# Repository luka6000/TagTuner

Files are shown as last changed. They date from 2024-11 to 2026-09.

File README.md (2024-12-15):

# TagTuner music player
TagTuner is a device that enables you to access music playlists or albums using NFC tags.\
It only works when integrated with Home Assistant media players and the Music Assistant music library is optional. This setup seamlessly blends your digital only music collection with the tactile experience of playing a physical record, tape or cd.\
Physical music media offer several advantages:

- it's easy
- it's fast
- it's inclusive

TagTuner is made with [ESPHome](https://www.esphome.io) and includes

- an NFC reader
- a dial
- a button
- a multicolor LED light

All of this is housed in a sleek, custom design case.
B71AED4C-08D7-4F52-AC81-285DC6743BAC

D1-Custom version is only 16mm high
66AA4F85-2C12-4B6F-A300-D6C1CED9CAEC_1_105_c

Here is an exploded view of the TagTuner 3D model with a round tag card \
35F8BCBF-CFB4-4F8B-A8F3-9931829DD101

## Getting started
To start using TagTuner, you’ll need the following:
- [Home Assistant](https://www.home-assistant.io) 2024.x
- [Music Assistant](https://music-assistant.io) 2.x or [Sonos](https://www.sonos.com/) speaker 
- configured MAss music [library](https://music-assistant.io/usage/#the-library) and/or a streaming subscription 
- TagTuner device configured in HAss
- Programmable NTAG213/215/216 tags

8D01B378-9F47-4FF3-8D71-280600690BE8_1_102_a

Assuming you already have Home Assistant (HAss) with Music Assistant (MAss) or Sonos set up and running, TagTuner supports [Improv via Serial](https://esphome.io/components/improv_serial) for Wi-Fi configuration.\
If the Wi-Fi connection is misconfigured, the device will start a Wi-Fi access point, allowing you to connect and set the password.\
Home Assistant will automatically detect your new TagTuner as ESPhome device.\
In the Diagnostic panel of TagTuner you can see detailed state of your device.\
Simply place any NFC tag and watch Status messages.\
A2F404BB-9D49-482E-803A-38D39FF03134

1CE9F457-F305-4B00-A466-14A5B7033EF4_1_102_a

## Using TagTuner
TagTuner relies heavily on Home Assistant automation. To get it working, import **TagTuner for HAss** blueprint



Create automation with this blueprint.\
Select your TagTuner device (you can have more than one!) and media player that will be your speaker \
AA88EF99-C0A6-40CE-A8F9-60A0C926069F

B459D72A-3B97-4AFB-BF86-19F3298A521F_1_102_a

### Playing music
Place your tag flat on the TagTuner or use the slot to position it nicely.\
TagTuner will read the tag and send the playlist information to Home Assistant. Using automation, HAss will play music on the speaker you've set up for this TagTuner.

### Button operations
**Single click**: next \
**Double click**: play/pause \
**Long click** (>1s): mute/unmute

### Volume control
Rotate the dial left: **volume down**. \
Rotate the dial right: **volume up**. 

### Feedback
Watch the LED light in the button: \
**white blink**: operation confirmed \
**flashing red**: writing operation in progress \
**flashing green**: writing success 

### Diagnostic
Check the Diagnostic->Status messages on the device page in Home Assistant.\
The ladybug icon is your guide.

AA29C1D0-BE96-452C-B2BF-FDD8AF05B9F1_1_102_a

## How to get tags for TagTuner
### Buy tags
Choose NTAG215 (504 bytes) or NTAG216 (888 bytes) tags if you want to include the playlist name and artist. Otherwise, NTAG213 (144 bytes) will suffice for just links to playlists

- [Plain white cards](https://s.click.aliexpress.com/e/_Deb0eeV)
- [Wooden cards](https://s.click.aliexpress.com/e/_DdGYnJf)
- [Round stickers](https://s.click.aliexpress.com/e/_DB8U8dB)

Stickers can be used with 3d printed cards or any other object you can place on your TagTuner to play music.\
I use Canon KC-18IF card-sized labels to customize my wooden NFC cards.

### Program tags for Music Assistant
If your speaker is one of Music Assistant media players, your tags need to have a MAss URI.\
[Here](https://music-assistant.io/faq/how-to/#get-the-uri) you can find instructions on how to get URI for the playlist or album you want.

On the TagTuner device page, you'll find all the fileds nesesary to write the playlist URI to your tag \
38842E5D-4B81-4B88-8815-FD35B67D8357

Minimum information needed is URI.\
Fill in the Playlist URI -> click _Write Tag_ -> LED starts flashing red -> Place the tag on TagTuner \
Successful writing will be confirmed with green light.\
Check Diagnostic->Status for any additional information.

### Program tags for Sonos
If your speaker is Sonos media player, your tags can have a plain HTTP playlist URL.\
[Here](https://support.apple.com/en-us/118235) you can find instructions on how to get the album or playlist url for Apple Music. Just copy it.\
It should work the same with [Spotify](https://support.spotify.com/us/article/share-from-spotify)

On the TagTuner device page, you'll find all the fileds nesesary to write the playlist URL (URI) to your tag \
15B48F29-212B-4739-B62A-51EE45BEE9E9

Minimum information needed is URL.\
Fill in the Playlist URL -> click _Write Tag_ -> LED starts flashing red -> Place the tag on TagTuner \
Successful writing will be confirmed with green light.\
Check Diagnostic->Status for any additional information.

### Other options
You can also write your tags with any NFC NDEF tag writer, such as NXP NFC TagWriter for [iOS](https://apps.apple.com/us/app/nfc-tagwriter-by-nxp/id1246143221) or [Android](https://play.google.com/store/apps/details?id=com.nxp.nfc.tagwriter)\

 or 


### More options
#### for Sonos
You can also play any Sonos app favorite playlist, album, or station!\
Simply write the name of the playlist or station exactly as it appears in the Sonos app.\
Then, enter sonos-2:// in the URI field.\
864038B7-970D-4120-AF52-DD503CA11BEE

#### for read-only tags
If you have any read-only tags that can be read by TagTuner (give it a try to check), you can use them too!\
To set the playlist URL, place it as the name of the tag in HAss panel \
\
D88754F6-5199-47EA-B71D-4B262B060160

Any tag id read by TagTuner will be pushed to HAss [blueprint](#using-tagtuner) automation.

8C579E90-8189-417C-8D1E-49295F2F88D9_1_102_a

## Build your own TagTuner
Choose and print your enclosure with preffered colors and surface patterns
150898D9-AA77-4470-9DA3-2A89EE304011

I suggest a cool white base and a dark front plate with a nice carbon fibre pattern.

### Parts for Atom grove version
This version is focused on minimum soldering since it's based on Grove parts and connectors
- [m5stack Atom Echo](https://s.click.aliexpress.com/e/_DCenStP) controller
- [pn532](https://s.click.aliexpress.com/e/_De8uw89) NFC reader
- [grove angle connectors](https://s.click.aliexpress.com/e/_DDF07mN)
- [grove cables](https://s.click.aliexpress.com/e/_DEA2jSV)
- [grove rotary encoder](https://www.seeedstudio.com/Grove-Encoder.html?sensecap_affiliate=3ftNV1d&referring_service=link)
#### Grove wiring
First, you need to solder the [grove angle connector](https://s.click.aliexpress.com/e/_DDF07mN) to the [PN532 NFC](https://s.click.aliexpress.com/e/_De8uw89) board
CA3A603C-CE5B-4982-AF24-9E40D3E554C2_1_201_a
Remember to set the DIP switches to 10 to enable I2C.

The [SeeedStudio rotary encoder](https://www.seeedstudio.com/Grove-Encoder.html?sensecap_affiliate=3ftNV1d&referring_service=link) already has its connector. For the other end of the [cable](https://s.click.aliexpress.com/e/_DEA2jSV), simply use [grove angle connector](https://s.click.aliexpress.com/e/_DDF07mN) directly to the Atom controller\
7D603FCA-9D48-485F-8AD4-685A469D73F6_1_201_a

It's really as simple as that
8CD41A9B-E7F6-46FE-8770-5138BF0B893E_1_201_a

Everything will fit into the enclosure.\
Use short (<5mm) M2 screw for Atom and longer (10mm) M2.5 screws for everything else (nfc board, volume encoder, front plate).
BD16EF90-5222-40EF-A131-2C27C6EE5493_1_102_o

### Parts for D1-Custom version
This version requires a bit more soldering but allows the knob to be used as a button.
- [esp32 D1 mini](https://s.click.aliexpress.com/e/_DkyEAwt) controller with USBC
- [pn532](https://s.click.aliexpress.com/e/_De8uw89) NFC reader
- [hw040](https://s.click.aliexpress.com/e/_DlIIMtn) rotary encoder

Remember to set the pn532 DIP switches to 10 to enable I2C (as described above).

#### Wiring D1-Custom
pn532 connector:
- GND: GND
- VCC: VCC (+5V)
- SDA/TXD: IO21
- SCL/RXD: IO22

hw040 connector:
- CLK: IO18
- DT: IO19
- SW: IO23
- +: +3.3V
- GND: GND

BCAC91FD-93C7-45B1-BD3F-C07717A7AF5C_1_201_a

ESP23 D1 mini will fit perfectly into the bottom part braces


Built-in LED is used as confirmation light
85EAFCF9-9730-4185-8AF7-A039E5863FB1_1_105_c

### Case options
- [3d models](https://github.com/luka6000/TagTuner/tree/main/3d%20models): Atom Echo Grove version 3d models
- [printables](https://www.printables.com/model/1109660-tagtuner-d1-custom1): 16mm D1-Custom version model

### Firmware options

- [tagtuner-atom-grove.yaml](https://github.com/luka6000/TagTuner/blob/main/tagtuner-atom-grove.yaml): based on m5stack Atom Echo and grove connectors
- [tagtuner-atom-grove-ble.yaml](https://github.com/luka6000/TagTuner/blob/main/tagtuner-atom-grove-ble.yaml): m5stack Atom Echo + Bluetooth & BLE proxy, no media player, ESP-IDF framework. This is current default install
- [tagtuner-for-tagreader.yaml](https://github.com/luka6000/TagTuner/blob/main/tagtuner-for-tagreader.yaml): TagTuner firmware for [Adonno tagreader](https://github.com/adonno/tagreader) device (buzzer only, no led support)
- [tagtuner-D1-custom1.yaml](https://github.com/luka6000/TagTuner/blob/main/tagtuner-D1-custom1.yaml): ESP32 D1 mini with HW-040 rotary encoder and button. Bluetooth & BLE proxy, ESP-IDF framework

## Help me
OK, I can try. Please choose your preferred way of communication

- [reddit](https://www.reddit.com/r/homeassistant/comments/1go2l9l/tagtuner_nfc_music_player_showoff/)
- [HAss community](https://community.home-assistant.io/t/tagtuner-music-player-for-nfc-tags/787529)
- [MAss discord](https://discord.com/channels/753947050995089438/1300230612958838908/1300230612958838908)

## A little history
It all began one day back in 2022. \
I've seen all those cool NFC jukebox projects but found myself too lazy to automate each tag individually. \
So, I [contributed](https://github.com/adonno/tagreader/commits?author=luka6000) to the Adonno [tagreader](https://github.com/adonno/tagreader) project to enable it to push playlist URLs as HAss events. \
[Here's](https://community.home-assistant.io/t/tagreader-jukebox-old-dog-new-tricks/407855) original story posted on Home Assistant communities.\
Since then, TagTuner has been completely refactored and physically redesigned.

## Disclaimer
All of this is my personal hobby project, available for free download and personal use. If you’d like to support me with a coffee, beer, filament, or electronic parts, feel free to use PayPal
[paypal.me/lukagra](http://paypal.me/lukagra)

Links to parts listed above are affiliate links, which allow me to earn a small commission from your purchase. Thank you! 🙏

My work, including yaml files, 3d model and documentation, is licensed under \
[Creative Commons (4.0 International License) Attribution—Noncommercial—Share Alike \
](http://creativecommons.org/licenses/by-nc-sa/4.0/)

ESPhome components modifications are licensed under ESPHome [license](https://github.com/esphome/esphome?tab=License-1-ov-file#readme)

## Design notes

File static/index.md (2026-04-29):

- [Firmware installation](#firmware-installation)
- [Getting started](#getting-started)
- [Build your own TagTuner](#build-your-own-tagtuner)
- [Using TagTuner](#using-tagtuner)
- [get tags for TagTuner](#how-to-get-tags-for-tagtuner)
- [Help](#help-me)

# TagTuner music player
TagTuner is a device that enables you to access music playlists or albums using NFC tags.\
It only works when integrated with Home Assistant media players. Music Assistant music library is optional. This setup seamlessly blends your digital only music collection with the tactile experience of playing a physical record, tape or cd.\
Physical music media offer several advantages:

- it's easy
- it's fast
- it's inclusive

TagTuner is made with [ESPHome](https://www.esphome.io) and includes

- an NFC reader
- a dial with a button
- a LED light

All of this is housed in a sleek, custom design case only 16mm high


66AA4F85-2C12-4B6F-A300-D6C1CED9CAEC_1_105_c

Here is an exploded view of the TagTuner 3D model with a round tag card \


TagTuner is a device approved by the [Made for ESPHome](https://devices.esphome.io/made-for-esphome) program.
made-for-esphome-black-on-white

Check out also the [TagTuner on HA Voice PE version](https://github.com/luka6000/TagTuner/blob/main/TagTuner-on-HA-Voice-PE.md)
2B7737D0-8398-4024-95F7-A9C97CBA63E3_1_105_c

## Firmware installation

You can use the button below to install the pre-built firmware directly to your device via USB from the browser.

<style>
  .invisible {
    visibility: hidden;
  }
  .radios li {
    list-style: none;
    line-height: 2em;
  }
</style>
<script type="module" src="https://unpkg.com/esp-web-tools@9/dist/web/install-button.js?module"></script>
<p>Select your TagTuner version</p>
<ul class="radios">
  <li>
    <label><input type="radio" name="type" value="tagtuner-xiao-esp32c6" /> XIAO Custom</label>
  </li>
  <li>
    <label><input type="radio" name="type" value="tagtuner-on-ha-voice-esp32s3" /> HA Voice PE</label>
  </li>
  <li>
    <label><input type="radio" name="type" value="tagtuner-atom-esp32" /> m5 Atom</label>
  </li>
  <li>
    <label><input type="radio" name="type" value="tagtuner-for-tagreader-esp8266" /> tagreader</label>
  </li>
  <li>
    <label><input type="radio" name="type" value="tagtuner-d1-esp32" /> D1 Custom</label>
  </li>
</ul>
<p class="button-row" align="center">
  <esp-web-install-button class="invisible"></esp-web-install-button>
</p>
<script>
  document.querySelectorAll('input[name="type"]').forEach(radio =>
    radio.addEventListener("change", () => {
      const button = document.querySelector('esp-web-install-button');
      button.manifest = `./firmware/manifest-${radio.value}.json`;
      button.classList.remove('invisible');
    }
  ));
</script>

Installer powered by [ESP Web Tools](https://esphome.github.io/esp-web-tools/)

## Getting started
To start using TagTuner, you’ll need the following:
- [Home Assistant](https://www.home-assistant.io) 2025.12.x
- [Music Assistant](https://music-assistant.io) 2.7.x or [Sonos](https://www.sonos.com/) speaker 
- configured MAss music [library](https://music-assistant.io/usage/#the-library) and/or a streaming subscription 
- TagTuner device configured in HAss
- any NFC tags or programmable NTAG213/215/216

8D01B378-9F47-4FF3-8D71-280600690BE8_1_102_a

Assuming you already have Home Assistant (HAss) with Music Assistant (MAss) or Sonos set up and running, TagTuner supports [Improv via Serial](https://esphome.io/components/improv_serial) and [Improv via BLE](https://esphome.io/components/esp32_improv) for Wi-Fi configuration.\
Home Assistant will automatically detect your new TagTuner as ESPhome device.\
In the Diagnostic panel of TagTuner you can see detailed state of your device.\
Simply place any NFC tag and watch Status messages.\
A2F404BB-9D49-482E-803A-38D39FF03134

1CE9F457-F305-4B00-A466-14A5B7033EF4_1_102_a

## Build your own TagTuner

### Case
Custom model cases are print-ready

- [printables](https://www.printables.com/model/1109660)
- [ko-fi/shop](https://ko-fi.com/s/ce428ab53f)

Choose and print your enclosure with preferred colors and surface patterns. \
I suggest a cool-white (signal white) base and a dark front plate with a nice carbon fibre pattern.
D7EFA920-1D9A-4D65-AD23-4F0A2328A510_1_105_c

### BOM for XIAO-Custom version
- [XIAO esp32-c6](https://s.click.aliexpress.com/e/_c3hnW7jV) controller with built-in antenna
- [pn532](https://s.click.aliexpress.com/e/_c3l9MKHr) NFC reader
- [grove angle connectors](https://s.click.aliexpress.com/e/_c3xcepEd)
- [grove cables](https://s.click.aliexpress.com/e/_c3rtIVGR)
- [hw040](https://s.click.aliexpress.com/e/_c3vSH4wJ) rotary encoder
- [dupont cables](https://s.click.aliexpress.com/e/_c4FUMZi7) for hw040
- [M2.5 10mm](https://s.click.aliexpress.com/e/_c3gFU5Zv) screws

#### Wiring XIAO-Custom
pn532 connector (use grove cable):
- GND: GND (bottom cable)
- VCC: VBUS (+5V, bottom cable)
- SDA/TXD: D4
- SCL/RXD: D5

hw040 connector (use dupont cable):
- CLK: D8
- DT: D9
- SW: D10
- +: 3V3 (+3.3V)
- GND: GND



Route and solder the VCC (red) and GND (white) wires along the bottom side of XIAO to ensure the front LED remains unobstructed.

XIAO will fit perfectly into the bottom part braces


Built-in LED is used as confirmation light. Print the led peg with clear filament and it will give great results \


I prefer soldering the grove angle connector to the PN532 NFC board
CA3A603C-CE5B-4982-AF24-9E40D3E554C2_1_201_a

Just use the force ;-)
528C987E-321C-4D8D-81F6-45F3D853613B_1_201_a

Remember to set the DIP switches to 10 to enable I2C. Correct switches position for I2c is marked by yellow lines.

Everything will fit into the enclosure.


Use 10mm M2.5 screws (nfc board, volume encoder, front plate).

### Firmware

- [quick start](https://luka6000.github.io/TagTuner/#installation): use pre-built firmware with [ESP Web Tools](https://esphome.github.io/esp-web-tools/) powered installer [here](https://luka6000.github.io/TagTuner/#installation)
- [tagtuner-XIAO-custom.yaml](https://github.com/luka6000/TagTuner/blob/main/tagtuner-XIAO-custom.yaml): XIAO ESP32-C6 with HW-040 rotary encoder and button. Bluetooth & BLE proxy, ESP-IDF framework

### Other options
- [D1 mini](https://github.com/luka6000/TagTuner/blob/main/TagTuner-D1.md): TagTuner Custom1 based on the ESP32 D1 Mini; previously my preferred version but dropped in favor of the XIAO because of the poor quality of available D1 boards
- [HA Voice PE version](https://github.com/luka6000/TagTuner/blob/main/TagTuner-on-HA-Voice-PE.md): TagTuner on HA Voice PE device
- [tagtuner-for-tagreader.yaml](https://github.com/luka6000/TagTuner/blob/main/tagtuner-for-tagreader.yaml): TagTuner firmware for [Adonno tagreader](https://github.com/adonno/tagreader) device (buzzer only, no led support)
- [Atom version](https://github.com/luka6000/TagTuner/blob/main/TagTuner-Atom.md): based on m5stack Atom Echo and grove connectors; free model case but much thicker (23.5mm)
- [Compact Case](https://www.printables.com/model/1165511-tagtuner-compact-case-rfid-nfc-scanner-home-assist): card-sized case by Youddha (thank you!)

## Using TagTuner
TagTuner relies heavily on Home Assistant automation. To get it working, import **TagTuner for HAss** blueprint



Create automation with this blueprint.\
Select your TagTuner device (you can have more than one!) and media player that will be your speaker \
AA88EF99-C0A6-40CE-A8F9-60A0C926069F

I do a monthly updates of the blueprint. You can watch my repo to get email notifications. \
Current list of features:

- separate settings for MAss player and HAss player (http sources). If you don't need double setting, just set the same player in both
- Stop music on tag removed: choose if you want this
- Announce every playlist: you can choose your TTS engine and TagTuner will use your speaker to read artist and playlist names
- Shuffle every playlist: choose if you want this. You can also add '/shuffle' (without quotes or spaces) at the end of the source URI to shuffle just this album
- Volume limiter: to limit the maximum volume set with TagTuner knob (kids friendly!)
- Default volume on start playing
- Notify about version mismatch: shoose if you want HA dashboard notification that your blueprint version is to new vs your TagTuner yaml firmware. Currently there are no breaking changes so this is future proofing the blueprint and your experience



B459D72A-3B97-4AFB-BF86-19F3298A521F_1_102_a

### Playing music
Place your tag flat on the TagTuner or use the slot to position it nicely.\
TagTuner will read the tag and send the playlist information to Home Assistant. Using automation, HAss will play music on the speaker you've set up for this TagTuner.

### Button operations
**Single click**: next \
**Double click**: play/pause \
**Long click** (>1s): mute/unmute \
**Triple click**: previous

### Volume control
Rotate the dial left: **volume down** \
Rotate the dial right: **volume up** 

### Feedback
Watch the LED light in the button: \
**blink**: operation confirmed \
**flashing constant**: writing operation in progress \
**flashing few times**: operation success

XIAO-Custom has a single color led so it's only blinking but it's really easy to understand what's going on. Use HAss device Diagnostic dashboard in case you would need status info.

### Diagnostic
Check the Diagnostic->Status messages on the device page in Home Assistant.\
The ladybug icon is your guide.

AA29C1D0-BE96-452C-B2BF-FDD8AF05B9F1_1_102_a

## How to get tags for TagTuner
### Upcycle tags you already have
Use whatever nfc tags you have that work with PN532. \
Simply scan them with TagTuner and check you HA tags panel. \
Try Amiibos, NFC rings, work badges, etc. \
You can even [recycle a Sonicare](https://github.com/luka6000/TagTuner/blob/main/Recycled-tags.md) toothbrush head 🤙

Check [the read-only tags](https://github.com/luka6000/TagTuner/tree/main?tab=readme-ov-file#for-read-only-tags) section below.

### Buy tags
Choose NTAG215 (504 bytes) or NTAG216 (888 bytes) tags if you want to include the playlist name and artist. Otherwise, NTAG213 (144 bytes) will suffice for just links to playlists

- [Plain white cards](https://s.click.aliexpress.com/e/_Deb0eeV)
- [Wooden cards](https://s.click.aliexpress.com/e/_DdGYnJf)
- [Round stickers](https://s.click.aliexpress.com/e/_DB8U8dB)

Record-like cards can be printed (model file included) or you can buy those nice looking [vinyl coasters](https://s.click.aliexpress.com/e/_ooVfjuN). Just remember to put NFC stickers on them ;-) \
Stickers can be used with 3d printed cards or any other object you can place on your TagTuner to play music.\
I use Canon KC-18IF card-sized labels to customize my wooden NFC cards.

### Program tags for Music Assistant
If your speaker is one of Music Assistant media players, your tags need to have a MAss URI.\
[Here](https://music-assistant.io/faq/how-to/#get-the-uri) you can find instructions on how to get URI for the playlist or album you want. In the latest versions you can basically copy the URI directly from the Provider details section for that media.

On the TagTuner device page, you'll find all the fileds nesesary to write the playlist URI to your tag \
38842E5D-4B81-4B88-8815-FD35B67D8357

Minimum information needed is URI.\
Fill in the Playlist URI -> click _Write Tag_ -> LED starts flashing red -> Place the tag on TagTuner \
Successful writing will be confirmed with green light.\
Check Diagnostic->Status for any additional information.

### Program tags for Sonos
If your speaker is Sonos media player, your tags can have a plain HTTP playlist URL.\
[Here](https://support.apple.com/en-us/118235) you can find instructions on how to get the album or playlist url for Apple Music. Just copy it.\
It should work the same with [Spotify](https://support.spotify.com/us/article/share-from-spotify)

On the TagTuner device page, you'll find all the fileds nesesary to write the playlist URL (URI) to your tag \
15B48F29-212B-4739-B62A-51EE45BEE9E9

Minimum information needed is URL.\
Fill in the Playlist URL -> click _Write Tag_ -> LED starts flashing red -> Place the tag on TagTuner \
Successful writing will be confirmed with green light.\
Check Diagnostic->Status for any additional information.

### Other options
You can also write your tags with any NFC NDEF tag writer, such as NXP NFC TagWriter for [iOS](https://apps.apple.com/us/app/nfc-tagwriter-by-nxp/id1246143221) or [Android](https://play.google.com/store/apps/details?id=com.nxp.nfc.tagwriter)\

 or 


### More options
#### for Sonos
You can also play any Sonos app favorite playlist, album, or station!\
Simply write the name of the playlist or station exactly as it appears in the Sonos app.\
Then, enter sonos-2:// in the URI field.\
864038B7-970D-4120-AF52-DD503CA11BEE

#### for read-only tags
If you have any read-only tags that can be read by TagTuner (give it a try to check), you can use them too!\
To set the playlist URL, place it as the name of the tag in HAss panel \
\
D88754F6-5199-47EA-B71D-4B262B060160

Any tag id read by TagTuner will be pushed to HAss [blueprint](#using-tagtuner) automation.

8C579E90-8189-417C-8D1E-49295F2F88D9_1_102_a

## Help
OK, I can try. Please choose your preferred way of communication

- [HAss community](https://community.home-assistant.io/t/tagtuner-music-player-for-nfc-tags/787529)
- [MAss discord](https://discord.com/channels/753947050995089438/1300230612958838908/1300230612958838908)
- [reddit](https://www.reddit.com/r/homeassistant/comments/1go2l9l/tagtuner_nfc_music_player_showoff/)

## A little history
It all began one day back in 2022. \
I've seen all those cool NFC jukebox projects but found myself too lazy to automate each tag individually. \
So, I [contributed](https://github.com/adonno/tagreader/commits?author=luka6000) to the Adonno [tagreader](https://github.com/adonno/tagreader) project to enable it to push playlist URLs as HAss events. \
[Here's](https://community.home-assistant.io/t/tagreader-jukebox-old-dog-new-tricks/407855) original story posted on Home Assistant communities.\
Since then, TagTuner has been completely refactored and physically redesigned.

## Disclaimer
All of this is my personal hobby project, available for free download and personal use. If you’d like to support me with a coffee, beer, filament, or electronic parts, feel free to use [paypal.me/lukagra](https://paypal.me/lukagra) or [ko-fi.com/lukagra](https://ko-fi.com/lukagra)

Links to parts listed above are affiliate links, which allow me to earn a small commission from your purchase. Thank you! 🙏

This work, including yaml files, 3d model (Atom version) and documentation, is licensed under \
[Creative Commons (4.0 International License) Attribution—Noncommercial—Share Alike \
](http://creativecommons.org/licenses/by-nc-sa/4.0/)

ESPhome components modifications are licensed under ESPHome [license](https://github.com/esphome/esphome?tab=License-1-ov-file#readme)

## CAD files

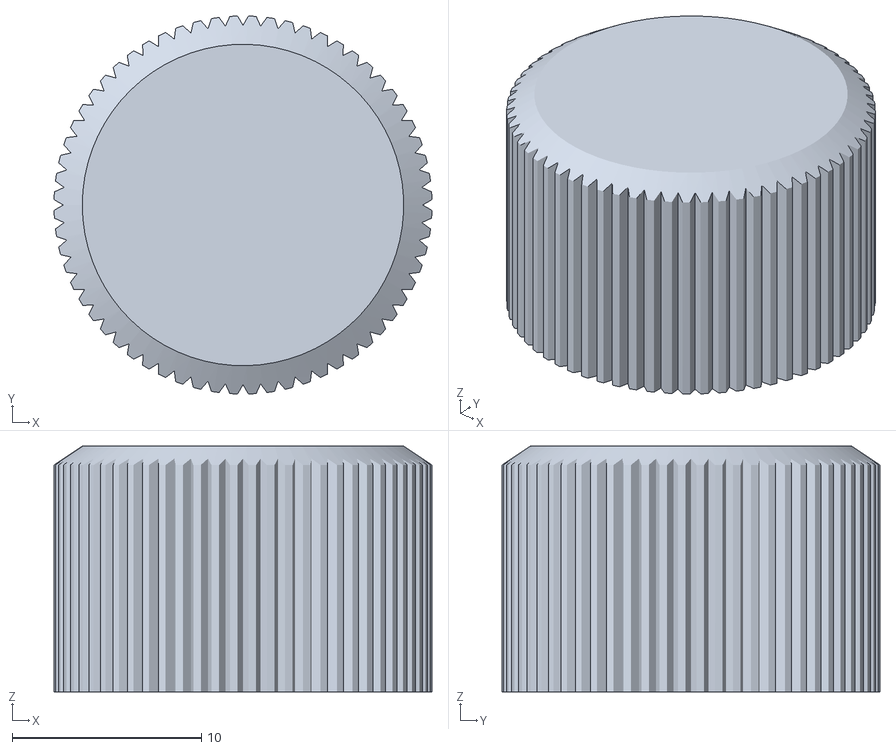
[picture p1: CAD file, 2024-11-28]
3d models/TagTunerVolumeKnob.stl
20.0 x 20.0 x 13.0

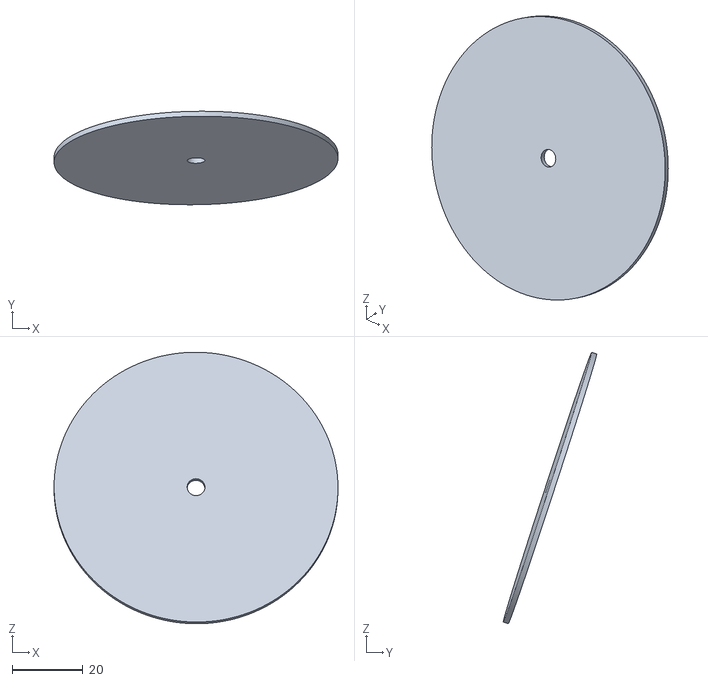
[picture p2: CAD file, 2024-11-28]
3d models/TagTunerRecordCard.stl
80.0 x 26.4 x 76.5

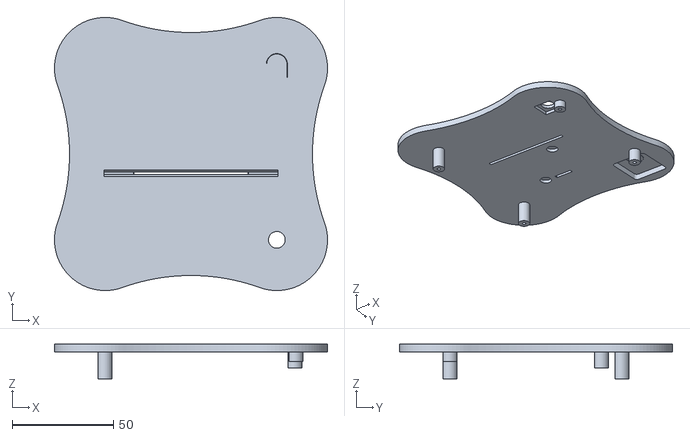
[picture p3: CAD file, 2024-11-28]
3d models/TagTunerAtomEchoGrovePlate.stl
134.9 x 134.9 x 17.2

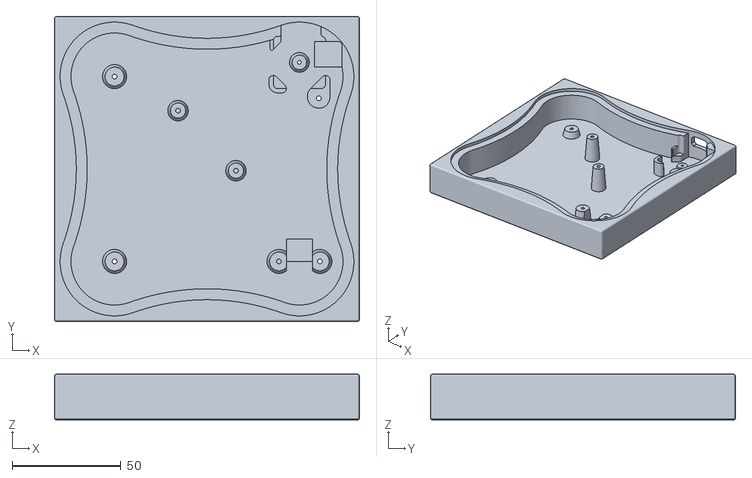
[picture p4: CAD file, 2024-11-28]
3d models/TagTunerAtomEchoGroveBase.stl
140.0 x 140.0 x 21.0

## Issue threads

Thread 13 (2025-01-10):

i2c configuration mismatch and incorrect screenshot of hardware settings nfc module

rbr101, 2025-01-10:
Hi Luka,

Nice work you did here, just tested the configuration and now printing the case.
I love the concept of a physical disk togerther with musicassistent.

I had to change the ic2 config to get it working:
```
i2c:
  id: bus_i2c
  sda: 21
  scl: 22
  scan: False
  frequency: 100kHz
  timeout: 13ms #to prevent pn532 timeout
```

Changed to:

```
i2c:
  id: bus_i2c
  scan: False
  timeout: 13ms #to prevent pn532 timeout
```

The frequency part was failing the NFC module to load (Probably because i’m using a clone NFC). Also in the screenshots in the docu the jumper setting is wrong and should be the other way around. In the screenshots SPI is selected but should be i2c.

I also found some nice mini vinyl LP’s on ali that can be used:  https://nl.aliexpress.com/item/1005008275356934.html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

My D1 esp32 does not have a green light ,  so i will probably add a ws2811 and a buzzer for feedback when writing /reading the tags.

Cheers!

luka6000, 2025-01-10:
Thanks.
Devices should hold 400kHz bus so this 100kHz is actually setting a slow bus. Hard to say why your nfc board can't keep up. Maybe set the timeout longer first.

About the screenshot: I think I know what you mean. It is set ok so I added clarification in the description
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

Nice finding with the retro vinyls. I'll add that to the options.
Good luck with your build and keep me posted.
Use latest blueprint since I do a monthly changes on that one!

Closed 2025-01-17.

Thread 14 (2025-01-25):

Issue after rebooting

pschneider87, 2025-01-25:
First of all, a huge thanks for your work. I've built everything with your manuals, and it worked very smooth.

I recently wanted to also make use of the BLE Proxy, so I decided to do a fresh start.
I've removed the esp project and added a new one, with a fresh install.

the new tagtuner.yaml which gets created already has some content:
```
esphome:
  name: tagtuner
  friendly_name: TagTuner

esp32:
  board: esp32dev
  framework:
    type: arduino

# Enable logging
logger:

# Enable Home Assistant API
api:
  encryption:
    key: "key is here"

ota:
  - platform: esphome
    password: "some password here"

wifi:
  ssid: !secret wifi_ssid
  password: !secret wifi_password

  # Enable fallback hotspot (captive portal) in case wifi connection fails
  ap:
    ssid: "Tagtuner Fallback Hotspot"
    password: "some other password"

captive_portal:
```

Is it correct to copy everything from [tagtuner-atom-grove-ble.factory.yaml](https://github.com/luka6000/TagTuner/blob/main/tagtuner-atom-grove-ble.factory.yaml) into my yaml and keep everything from my configuration? Of course I substitute the esp32: section with the one from the yaml

```
esp32:
  board: m5stack-atom
  framework:
    type: esp-idf
```

So far, everything works smooth and I can use it in the beginning.
But as soon as I unplug it and bring it to it's final destination and try to restart it, it won't come back to life.

I can connect to the tagtuner and see some logs:

```
INFO ESPHome 2024.12.4
INFO Reading configuration /config/esphome/tagtuner.yaml...
INFO Updating https://github.com/luka6000/TagTuner.git@main
INFO Starting log output from 192.168.178.164 using esphome API
INFO Successfully connected to tagtuner @ 192.168.178.164 in 0.042s
INFO Successful handshake with tagtuner @ 192.168.178.164 in 0.107s
[13:40:37][I][app:100]: ESPHome version 2024.12.4 compiled on Jan 25 2025, 13:24:46
[13:40:37][C][wifi:600]: WiFi:
[13:40:37][C][wifi:428]:   Local MAC: 14:2B:2F:A0:5D:28
[13:40:37][C][wifi:433]:   SSID: [redacted]
[13:40:37][C][wifi:436]:   IP Address: 192.168.178.164
[13:40:37][C][wifi:440]:   BSSID: [redacted]
[13:40:37][C][wifi:441]:   Hostname: 'tagtuner'
[13:40:37][C][wifi:443]:   Signal strength: -39 dB ▂▄▆█
[13:40:37][C][wifi:447]:   Channel: 1
[13:40:37][C][wifi:448]:   Subnet: 255.255.255.0
[13:40:37][C][wifi:449]:   Gateway: 192.168.178.1
[13:40:37][C][wifi:450]:   DNS1: 192.168.178.1
[13:40:37][C][wifi:451]:   DNS2: 0.0.0.0
[13:40:37][C][logger:185]: Logger:
[13:40:37][C][logger:186]:   Level: DEBUG
[13:40:37][C][logger:188]:   Log Baud Rate: 115200
[13:40:37][C][logger:189]:   Hardware UART: UART0
[13:40:37][C][captive_portal:089]: Captive Portal:
[13:40:37][C][mdns:116]: mDNS:
[13:40:37][C][mdns:117]:   Hostname: tagtuner
[13:40:37][C][esphome.ota:073]: Over-The-Air updates:
[13:40:37][C][esphome.ota:074]:   Address: tagtuner.local:3232
[13:40:37][C][esphome.ota:075]:   Version: 2
[13:40:37][C][esphome.ota:078]:   Password configured
[13:40:37][C][safe_mode:018]: Safe Mode:
[13:40:37][C][safe_mode:020]:   Boot considered successful after 60 seconds
[13:40:37][C][safe_mode:021]:   Invoke after 10 boot attempts
[13:40:37][C][safe_mode:023]:   Remain in safe mode for 300 seconds
[13:40:37][C][api:140]: API Server:
[13:40:37][C][api:141]:   Address: tagtuner.local:6053
[13:40:37][C][api:143]:   Using noise encryption: YES
[13:40:48][D][api:103]: Accepted 192.168.178.36
[13:40:48][W][component:237]: Component api took a long time for an operation (70 ms).
[13:40:48][W][component:238]: Components should block for at most 30 ms.
[13:40:48][D][api.connection:1446]: Home Assistant 2025.1.4 (192.168.178.36): Connected successfully
[13:41:15][I][safe_mode:041]: Boot seems successful; resetting boot loop counter
[13:41:15][D][esp32.preferences:114]: Saving 1 preferences to flash...
[13:41:15][D][esp32.preferences:143]: Saving 1 preferences to flash: 0 cached, 1 written, 0 failed
```

There's nothing more happening.

Any idea?

luka6000, 2025-01-25:
> First of all, a huge thanks for your work. I've built everything with your manuals, and it worked very smooth.
>

Glad it works for you as designed!

> Is it correct to copy everything from [tagtuner-atom-grove-ble.factory.yaml](https://github.com/luka6000/TagTuner/blob/main/tagtuner-atom-grove-ble.factory.yaml) into my yaml and keep everything from my configuration? Of course I substitute the esp32: section with the one from the yaml
>

No. Use just the tagtuner-atom-grove-ble.factory.yaml file.
You could leave "api" and "ota" section. Please remove "captive_portal" and "ap:" in the "wifi" section as these take a lot of memory.
Remember to flush with usb for the first time and setup wifi. Later you can use wireless update (ota).

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

These logs look pretty standar.

> There's nothing more happening.
> Any idea?

What do you mean? Is this node recognized by HAss? Please remove old tagtuner node and discover it again.
Can you see esphome.tagtuner events in the HAss Developer tools->Events (start listening for those events) after trying to scan the tag?

Closed 2025-03-21.

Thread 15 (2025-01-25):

Example URI for "ytmusic://" ? Thanks!

Youddha, 2025-01-25:
Hello,
First of all thanks a lot for the project ! I really like it and it work very nicely.

I would like to know if you could provide an example an how to find/enter the uri for **"ytmusic://"** ? And where to find the info ? I tried almost every combination of the indication given in mass docs with no luck...

Unrelated:
- I can confirm that **tidal://** and **filesystem_local://** URIs work great !
- I will soon publish a compact 3D case for the WemosD1/ESP32: [this one](https://www.printables.com/make/2350666). Hope it will help a bit user of your project that want Card-sized scanner.

luka6000, 2025-01-25:
So, first things first:

1. YTmusic support in MAss is reverse engineering private yt api. This means it is not guaranteed to be always working. In fact, it is guaranteed to fail from time to time. Here's [MAss yt docs](https://www.music-assistant.io/music-providers/youtube-music/) confirming this situation
2. Lately ytmusic was not working for me but now I've checked it is working again. I've used method described in [MAss docs](https://www.music-assistant.io/faq/how-to/#get-the-uri). Using "Music Assistant: Search Music Assistant" action in HAss I was able to get ytmusic uris like this ytmusic://track/yl3TsqL0ZPw
3. This method of getting URI is very complicated and not clear. Here is a github feature request so you can discuss it with MAss developers https://github.com/orgs/music-assistant/discussions/2311
4. In case you have problems with getting URI, please ask for support on MAss github or discord. MAss developers have their own priorities and apparently getting URI easy is one of them.
5. What I can recommend is this: set your own MAss playlist (URI will look like library://track/127) and add ytmusic tracks to it. Of course, there is no other way of getting this local URI then searching it with HAss action 🤦‍♂️🤷‍♂️ This way at least the URI is constant and on local side. As a side bonus you can change track order however you like.
6. apple_music:// URIs also work great but have to be searched for with MAss service.
7. https direct links to playlist, tracks, album and everything work great with Sonos (not using MAss at all)

Cool looking mini reader. Can I ask you to also link my main page (https://luka6000.github.io/TagTuner/) in your model description? I'm glad you enjoy using TagTuner blueprint!

Youddha, 2025-01-27:
Hello,

Thanks a lot for your detailed answer and advices. I see you have been busy on the MAss github too.
I'll try your solutions 2 and 5 asap thanks.
Lastly, I posted my model yesterday on[ Printable.com](https://www.printables.com/model/1165511-tagtuner-compact-case-rfid-nfc-scanner-home-assist) and I off course referenced your project !

_Will update on 2 and 5 soon._

Closed 2025-02-03.

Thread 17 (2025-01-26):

Compact Case available on Printable

Youddha, 2025-01-26:
Hello Luka,

I really like your project and I designed a compact case for it. Here it is:
[https://www.printables.com/model/1165511-tagtuner-compact-case-rfid-nfc-scanner-home-assist](https://www.printables.com/model/1165511-tagtuner-compact-case-rfid-nfc-scanner-home-assist)

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

I understand it is not an "issue" per say but I don't know how to reach you in another way ^^

Hope it helps your project !

luka6000, 2025-02-03:
made it part of the new main readme page. Thank you!

Closed 2025-02-03.

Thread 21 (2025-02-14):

Trouble installing on tagreader hardware

kylebjordahl, 2025-02-14:
Hey @luka6000,

First of thanks for all the effort on this, it's super cool!

I'm somewhat new to ESPHome, so this could be me being naive, but I'm having trouble installing the `tagtuner-for-tagreader` firmware version; here's what I've done so far:
 - I've directly copied the `tagtuner-for-tagreader.factory.yaml` from main ( [12f0eaa](https://github.com/luka6000/TagTuner/commit/12f0eaac054a88a42bd3ffabe5616236721c261d)) and I seem to be getting an error about missing a substitution for `magic`.
 - Hoping to work around this, I found a substitution defined for this in the `tagtuner-project.yaml` file, so I tried just dropping that into the yaml to see what happens, and now when scanning a tag I get a tone from the buzzer that lasts for ~5 seconds, which makes me think this is not a viable patch.
 - I then switched the logging level in the yaml to `VERBOSE` and re-uploaded the firmware, and now I can see a ton in the logs (and get no buzzer when scanning) but a scan now results in an OOM panic. These logs and my latest YAML are below

## YAML
```yaml
# These substitutions allow the end user to override certain values
substitutions:
  name: tagtuner-4ab0f8
  friendly_name: Living Room TagTuner 4ab0f8
  d1_mini: d1_mini
  buzpin: D7
  ledpin: D8
  magic: "250105"

esphome:
  name: ${name}
  friendly_name: ${friendly_name}
  # Automatically add the mac address to the name
  # so you can use a single firmware for all devices
  name_add_mac_suffix: false

  # hello world
  on_boot:
    priority: -100
    then:
    - wait_until:
        condition:
          api.connected:
        timeout: 20s
    - text_sensor.template.publish:
        id: status
        state: Ready
    # - light.turn_off: led1

esp8266:
  board: $d1_mini
  framework:
    version: recommended

# To be able to get logs from the device via serial and api.
logger:
   level: VERBOSE
  # level: DEBUG
  # level: WARN
  # level: ERROR
  # logs:
  #   light: WARN
  #   pn532: DEBUG
  #   pn532_i2c: DEBUG

packages:
  core-nfc: github://luka6000/TagTuner/tagtuner-core-nfc.yaml@main
  core-comms: github://luka6000/TagTuner/tagtuner-core-comms.yaml@main
  # I was not able to use light with tagreader hardware and TagTuner firmware.
  # My nodemcu is restarting every time I try to turn on the light.
  # Please experiment on your own.
  # tagreader-light: !include tagtuner-for-tagreader-light.yaml

i2c:
  id: bus_i2c
  scan: false
  frequency: 100kHz
  timeout: 13ms #to prevent pn532 timeout

output:
- platform: esp8266_pwm
  pin: $buzpin
  id: buzzer

rtttl:
  output: buzzer
  id: buz

switch:
- platform: template
  name: Buzzer Enabled
  id: buzzon
  icon: mdi:volume-high
  optimistic: true
  restore_mode: RESTORE_DEFAULT_ON
  entity_category: config

#Enable light and check if it works for you. My nodemcu keeps restarting with light enabled.
script:
- id: led_blink
  then:
  - if:
      condition:
        switch.is_on: buzzon
      then:
      - rtttl.play: write:d=24,o=5,b=100:g,b
    # - if:
    #     condition:
    #       switch.is_on: ledon
    #     then:
    #     - light.turn_on:
    #         id: led1
    #         effect: blinkWhite
    #     - delay: 600ms
    #     - light.turn_off: led1
- id: led_ok
  then:
  - if:
      condition:
        switch.is_on: buzzon
      then:
      - rtttl.play: success:d=24,o=5,b=100:c,g,b
    # - if:
    #     condition:
    #       switch.is_on: ledon
    #     then:
    #     - light.turn_on:
    #         id: led1
    #         effect: blinkGreen
    #     - delay: 600ms
    #     - light.turn_off: led1
- id: led_success
  then:
  - if:
      condition:
        switch.is_on: buzzon
      then:
      - rtttl.play: write:d=24,o=5,b=100:b,b
    # - if:
    #     condition:
    #       switch.is_on: ledon
    #     then:
    #     - light.turn_on:
    #         id: led1
    #         effect: blinkGreen
    #     - delay: 600ms
    #     - light.turn_off: led1
- id: led_tagwrite
  then:
  - if:
      condition:
        switch.is_on: buzzon
      then:
      - rtttl.play: write:d=24,o=5,b=100:b
    # - if:
    #     condition:
    #       switch.is_on: ledon
    #     then:
    #     - light.turn_on:
    #         id: led1
    #         effect: blinkRed
```

## Logs
```
[22:11:03][V][pn532_i2c:040]: Reading response
[22:11:03][V][pn532:305]: Sending NACK for retransmit
[22:11:03][V][pn532_i2c:046]: Reading response of length 14
[22:11:03][D][pn532:367]: Mifare ultralight
[22:11:03][V][pn532:284]: Reading ACK...
[22:11:03][V][pn532:295]: ACK valid: YES
[22:11:03][V][pn532_i2c:040]: Reading response
[22:11:03][V][pn532:305]: Sending NACK for retransmit
[22:11:03][V][pn532_i2c:046]: Reading response of length 18
[22:11:03][V][pn532:284]: Reading ACK...
[22:11:03][V][pn532:295]: ACK valid: YES
[22:11:03][V][pn532_i2c:040]: Reading response
[22:11:03][V][pn532:305]: Sending NACK for retransmit
[22:11:03][V][pn532_i2c:046]: Reading response of length 18
[22:11:03][V][pn532:284]: Reading ACK...
[22:11:03][V][pn532:295]: ACK valid: YES
[22:11:03][V][pn532_i2c:040]: Reading response
[22:11:03][V][pn532:305]: Sending NACK for retransmit
[22:11:03][V][pn532_i2c:046]: Reading response of length 18
[22:11:03][V][pn532:284]: Reading ACK...
[22:11:03][V][pn532:295]: ACK valid: YES
[22:11:03][V][pn532_i2c:040]: Reading response
[22:11:03][V][pn532:305]: Sending NACK for retransmit
[22:11:03][V][pn532_i2c:046]: Reading response of length 18
[22:11:03][V][pn532:284]: Reading ACK...
[22:11:03][V][pn532:295]: ACK valid: YES
[22:11:03][V][pn532_i2c:040]: Reading response
[22:11:03][V][pn532:305]: Sending NACK for retransmit
[22:11:03][V][pn532_i2c:046]: Reading response of length 18
[22:11:03][V][pn532:284]: Reading ACK...
[22:11:03][V][pn532:295]: ACK valid: YES
[22:11:03][V][pn532_i2c:040]: Reading response
[22:11:03][V][pn532:305]: Sending NACK for retransmit
[22:11:03][V][pn532_i2c:046]: Reading response of length 18
[22:11:03][V][nfc.ndef_message:010]: Building NdefMessage with 86 bytes
[22:11:03][V][nfc.ndef_message:074]: Adding record type T = TagTuner
[22:11:03][V][nfc.ndef_message:074]: Adding record type T = artist/ Raffi
[22:11:03][V][nfc.ndef_message:074]: Adding record type T = playlist/
[22:11:03][V][nfc.ndef_message:074]: Adding record type U =  apple_music://artist/2477772
[22:11:03][D][main:456]: on_tag
[22:11:03][D][binary_sensor:036]: '=Tag=': Sending state ON
[22:11:03][V][text_sensor:013]: 'Status': Received new state Tag 04-05-58-97-79-00-00
[22:11:03][D][text_sensor:064]: 'Status': Sending state 'Tag 04-05-58-97-79-00-00'
[22:11:03]
[22:11:03]User exception (panic/abort/assert)
--------------- CUT HERE FOR EXCEPTION DECODER ---------------
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
luka6000, 2025-02-14:
yes, i've also been struggling with oom on my 8266. And since I don't have original Adonno reader it's a bit of a hit and miss on my side. My NodeMCU 8266 is very similar but not the same.

Looking at the yaml, this will not work. There is a lot going on with nfc code as I'm focusing on esp32.
But since I'm using 8266 for one of my readers I've figured out this "memory constraint" version yaml https://github.com/luka6000/TagTuner/blob/ha-voice-pe/tagtuner-for-tagreader.factory.yaml
The most crucial part is this:
```
wifi:
  ap: !remove
captive_portal: !remove

button:
  - id: !remove btn_erase_tag
  - id: !remove btn_cancel_writing
script:
  - id: !remove action_event
```
which actually removes some of the features but keeps the reader at reasonably usable level.
Also keep the log level as low as possible (ERROR, CRITICAL or NONE) since rising the logging increases code size.

Your best bet I can recommend is installing directly from here https://luka6000.github.io/TagTuner/#installation Just remember to set up wifi with the same connection (it will ask you to do it).
This should allow you to use tagreader in ha without changing to code. In case you are concerned about security of the code, here you can find the build logs for this publish https://github.com/luka6000/TagTuner/actions/runs/13122459602

Your second option and if you want to build your own firmware is to work with this yaml https://github.com/luka6000/TagTuner/blob/ha-voice-pe/tagtuner-for-tagreader.factory.yaml

And about the "magic" number: it's just a way to check if esphome firmware is compatible with HA blueprint. But since there are no breaking changes yet, you can turn off the warning in the blueprint options.

kylebjordahl, 2025-02-18:
OK, first of all, I feel a bit foolish; I use Safari primarily, and didn't even realize that your GH pages site had a firmware installer built in (I clearly just skimmed that part since there was no big obvious button). I had poked around previously and found the Actions workflow that creates the firmware and thought to myself "huh, wonder what that gets used for" 🤦 . Now that I've used Chrome, it's far more obvious how to install from your builds!

I tried the direct install and still no luck with the Adonno ; I've also got some D1s and spare parts around and I've built one so far which is working fine. If I ever get around to poking the Adonno more, I'll let you know (and maybe PR a suggestion if I have one).

Thanks again for making such a cool thing, and thanks for responding to my question!

Closed 2025-02-18.

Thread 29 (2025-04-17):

Playlists Immediately Stopping after Starting

RemakingEden, 2025-04-17:
Hi,

First off, thanks for all the hard work. Im really impressed and im going to be so happy once this is working correctly for me :)

## Issue
I place a card on the reader and a playlist starts playing but then after an indeterminable amount of time stops playing. Within Music Assistant it still shows as playing and if I pause and play again it will play for some more seconds.

## My setup
- Tag Tuner Voice PE Edition
- Spotify Playlist
- Firmware that piggybacks on Voice PE

Im not sure what logs you will require so please let me know and i'll be happy to attach them!

RemakingEden, 2025-04-17:
Ive switched to the regular firmware and this seems to have solved the problems

luka6000, 2025-04-17:
I'm not sure if I understand correctly but I'm glad it works for you!

RemakingEden, 2025-04-24:
Its working flawlessly now @luka6000. Thanks!

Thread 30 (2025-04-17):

[Enhancement] Write all NFC Records to log

Danos0100, 2025-04-17:
To make the TagTuner reader more versatile, i suppose writing all records on the nfc tag to the log, so different records can be used by different automations. The lambda code of the on_tag function could look like this, with `id(records_out)` being added to the `tagtuner_event`.
```
     - lambda: |-
        id(playlist)="";
        id(artist)="";
        id(uri)="";
        if (tag.has_ndef_message()) {
          std::string out = "[";
          bool first = true;
          for (auto &record : tag.get_ndef_message()->get_records() ) {
            std::string payload = record->get_payload();
            std::string type = record->get_type();
            if ( payload.substr(0, 7) == "artist/" ) {
              id(artist)=payload.substr(7);
            }

            else if ( payload.substr(0, 9) == "playlist/" ) {
              id(playlist)=payload.substr(9);
            }                                     
            else if (type == "U"
            && payload.substr(0, 20) != "https://mb.senic.com"
            && payload.substr(0, 23) != "https://www.philips.com"
            ) {
              id(uri)=payload;
            }
            if (!first) out += ",";
            out += "{\"type\":\"" + record->get_type() + "\",";
            out += "\"payload\":\"" + record->get_payload() + "\"}";
            first = false;
          }
          out += "]";
          id(records_out) = out;
        }
```
Now, all records can be accessed using something like `"{{ (trigger.event.data.records | from_json | selectattr('payload', 'search', 'lorem') | list).0.payload[6:] }}"` for a text record like `lorem/Lorem ipsum dolor sit amet`

However with the current code, this only works if a url record is placed on the tag, because with no url record present, the plain uid tag event will be triggered instead of the tagtuner_event (which is, on the other hand, needed for using TagTuner in its intended usecase)

Danos0100, 2025-04-19:
Hi, my desired usecase is kinda special. I want to control wled using nfc tags, but actually write the api calls to execute on the tags themselves rather than doing some tag name → api call matching in home assistant. Of course, I can simply use the artist, playlist and uri fields and modify the blueprint, but I thought, reading additional records that were written using a phone (Text record 'custom/………' for example) would be a nice feature. As I am on an ESP32 and not an ESP8266, I tried a forked version of adonno's tagreader (https://github.com/leinich/tagreader), but was not able to read the tags' content, so I tried TagTuner and found it quite useful for my usecase.

However, I definitely understand your point concerning the memory issues. Actually, even with a completely unmodified version of TagTuner on an esp32 (!), writing URI records close to the 255 character limit crashes the esp, apparently because it takes too long and makes the watchdog reboot the esp, even reading long records written using a phone crashes the esp (could this be fixed by increasing some time limits?)

luka6000, 2025-05-03:
ok, got it. So in this case I would recommend you take a look at how I solved read-only tags.
Write your api in the tag name in HA and do automation base on tag name. This way you are not doing tag id matching since this is handled by HA for you. You just do your automation based on tagscanned event and tag name.

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

Danos0100, 2025-05-04:
Yeah, I've seen that possibility. I ended up with using the url field and the artist field and a custom blueprint automation, while carefully trying to keep the data on the nfc tag low. The largest limitation seems to be esphome failing to read tags with too much information, above ca. 260 bytes or so, there's a message about the NDEF record being faulty and if you increase the content even more, the device reboots – even on an esp32, regardless of the chosen firmware (tagtuner or tagreader).

Closed 2025-05-04.

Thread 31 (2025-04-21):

[Feature Request] Change track on tag lift and replace

teetery, 2025-04-21:
Hi @luka6000. My kids and I love this project! We've repurposed a bunch of Disney Infinity Power Discs as albums and playlists, and they're cheap to get in bulk on eBay. The kids also like to make statues out of model magic and pop in a Sonicare tag for their own playlists.

I have one feature request from the kids, and I'm not sure if this is something you could implement easily in the blueprint or not. Basically, I'd like to be able to skip to the next track in a playlist or album by lifting and replacing the same tag within a short interval (like <2 seconds). A couple taps of the tag get you to the desired track. This means we can skip tapping the knob (we actually are knob-free in our implementation.)

Regardless, rockin' work, thanks!

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

luka6000, 2025-05-03:
I just love what you've done with those Infinity discs! Gotta check them out on ebay.
Let me see if I can do skip track on tag replacing.

luka6000, 2025-05-03:
it's done #33 and merged. Re-import your HA blueprint and let me know. Cheers!

teetery, 2025-05-03:
Just updated the blueprint. This works brilliantly! We've tested this on a few playlists. Even skipping halfway through works just fine. I see you added a 3 second timeout so if the disc is off for more than 3 seconds it restarts at the beginning of the list. Thanks for your work. I've attached one more photo of my setup. I had a couple HA Voice Previews and some Atom Echos in a drawer. The atom echo and scanner fits in the HA Voice box (even has a round indicator of where to set the disc (ha!). And I removed the speaker from the HA Voice and placed the NFC reader in the bottom of the case. Now it sits upside down on the shelf.

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

Closed 2025-10-05.

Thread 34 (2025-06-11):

Instable - Wifi disconnect when card reading

iambusdi, 2025-06-11:
Hi,
first of all – thank you for this very cool project! I'm currently building a device for my kids' room and really enjoy working with it.

I’ve soldered all the parts and assembled everything into the 3D model you offered on ko-fi. In my workspace, the setup works perfectly. However, I'm encountering a strange issue when I move the device to my kids’ room:

🛠️ Problem Description
When I place an NFC card on the reader, the music playback starts as expected – but then the Wi-Fi connection drops until I remove the card again.
During this time:
- The music continue playing.
- The LED keeps blinking as long as the card is present.
- Volume control doesn’t work either (due to the missing Wi-Fi connection, I assume).

To investigate further, I added a simple Wi-Fi signal quality sensor to the code.
Here are the signal strengths I observed:
   workspace: ~ -60 dB
   Kids’ room: ~ -70 dB
Both values seem relatively stable, though a bit weaker in the kids’ room.

Also the ping (every 1s) is gone and higher after removing the card for some time:
```
64 bytes from : icmp_seq=27179 ttl=64 time=84.394 ms
64 bytes from xx.xx.xx.xx: icmp_seq=27180 ttl=64 time=102.638 ms
64 bytes from xx.xx.xx.xx: icmp_seq=27181 ttl=64 time=9.436 ms      <- add card
Request timeout for icmp_seq 27182
....
Request timeout for icmp_seq 27209                                                      <- remove card
64 bytes from xx.xx.xx.xx: icmp_seq=27183 ttl=64 time=27819.006 ms
64 bytes from xx.xx.xx.xx: icmp_seq=27184 ttl=64 time=26820.371 ms
64 bytes from xx.xx.xx.xx: icmp_seq=27185 ttl=64 time=25815.771 ms
64 bytes from xx.xx.xx.xx: icmp_seq=27186 ttl=64 time=24810.971 ms
64 bytes from xx.xx.xx.xx: icmp_seq=27187 ttl=64 time=23814.802 ms
64 bytes from xx.xx.xx.xx: icmp_seq=27188 ttl=64 time=22812.565 ms
64 bytes from xx.xx.xx.xx: icmp_seq=27189 ttl=64 time=21808.458 ms
64 bytes from xx.xx.xx.xx: icmp_seq=27190 ttl=64 time=20806.192 ms
64 bytes from xx.xx.xx.xx: icmp_seq=27191 ttl=64 time=19804.780 ms
64 bytes from xx.xx.xx.xx: icmp_seq=27192 ttl=64 time=18800.879 ms
64 bytes from xx.xx.xx.xx: icmp_seq=27202 ttl=64 time=8845.367 ms
64 bytes from xx.xx.xx.xx: icmp_seq=27211 ttl=64 time=103.726 ms
64 bytes from xx.xx.xx.xx: icmp_seq=27212 ttl=64 time=116.920 ms
64 bytes from xx.xx.xx.xx: icmp_seq=27213 ttl=64 time=144.283 ms
64 bytes from xx.xx.xx.xx: icmp_seq=27214 ttl=64 time=54.370 ms
64 bytes from xx.xx.xx.xx: icmp_seq=27215 ttl=64 time=2.547 ms
64 bytes from xx.xx.xx.xx: icmp_seq=27216 ttl=64 time=4.746 ms
```

❓ Do you have any idea how to solve this issue?
Do you have any ideas what could cause this issue – especially the Wi-Fi disconnect triggered specifically by placing the NFC card?
Could it be interference, shielding, or maybe power-related (tested different usb charger up to 10W)?
I am using this esp32 mini USB-C version.
https://www.amazon.de/dp/B0D7V9591B?ref=ppx_yo2ov_dt_b_fed_asin_title&th=1

Thank you for your support!

🔧 Optional: Wi-Fi Quality Sensor Code
If you're interested in adding a similar Wi-Fi signal check to your project, I based mine on the following config:
https://github.com/jcallaghan/esphome-config

config file:
```
sensor:
  - <<: !include ../sensors/wifi_signal_percentage.yaml
  - <<: !include ../sensors/wifi_signal.yaml
    on_value:
      - component.update: sensor_wifi_signal_percentage

text_sensor:
  - <<: !include ../text_sensors/wifi_info.yaml
```

wifi_signal_percentage.yaml
```
---
# WiFi Signal Percentage Sensor
#
# A template sensor that calculates the Wi-Fi Signal Strength as a percentage.
#
# This template doesn't update by itself. It is used by:
# common/wifi.yaml
#
# https://esphome.io/components/sensor/wifi_signal.html
#
platform: template
id: sensor_wifi_signal_percentage
name: "WiFi Signal Percentage - ${name}"
icon: "mdi:wifi"
unit_of_measurement: "%"
update_interval: never
lambda: |-
  if (id(sensor_wifi_signal).state) {
    if (id(sensor_wifi_signal).state <= -100 ) {
      return 0;
    } else if (id(sensor_wifi_signal).state >= -50) {
      return 100;
    } else {
      return 2 * (id(sensor_wifi_signal).state + 100);
    }
  } else {
    return NAN;
  }
```

wifi_signal.yaml
```
# WiFi Signal Sensor
#
# The wifi_signal sensor platform allows you to read the signal strength of the
# currently connected WiFi Access Point.
#
# https://esphome.io/components/sensor/wifi_signal.html
#
platform: wifi_signal
id: sensor_wifi_signal
name: "WiFi Signal - ${friendly_name} (${system_id})"
update_interval: 300s
```

wifi_info.yaml
```
---
# WiFi Info Text Sensor
#
# The wifi_info text sensor platform exposes different WiFi information via
# text sensors.
#
# https://esphome.io/components/text_sensor/wifi_info.html
#
platform: wifi_info
ip_address:
  name: "IP Address - ${friendly_name} (${system_id})"
ssid:
  name: "SSID - ${friendly_name} (${system_id})"
bssid:
  name: "BSSID - ${friendly_name} (${system_id})"
mac_address:
  name: "MAC - ${friendly_name} (${system_id})"
```

iambusdi, 2025-06-12:
looks like this could be a similar issue
no tests done until now
https://github.com/adonno/tagreader/issues/222

RemakingEden, 2025-09-16:
Yeah I can second this. Ive stopped using the VPE one as I was getting disconnections and stuttering in the music. I dissassembled and moved the NFC reader away and it became stable.

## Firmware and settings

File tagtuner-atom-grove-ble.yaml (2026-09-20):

packages:
  # project: github://luka6000/TagTuner/tagtuner-project.yaml@main
  # core-nfc: github://luka6000/TagTuner/tagtuner-core-nfc.yaml@main
  # core-comms: github://luka6000/TagTuner/tagtuner-core-comms.yaml@main
  project: !include tagtuner-project.yaml
  core-nfc: !include tagtuner-core-nfc.yaml
  core-comms: !include tagtuner-core-comms.yaml

# These substitutions allow the end user to override certain values
substitutions:
  name: "tagtuner"
  friendly_name: "TagTuner"

esphome:
  name: "${name}"
  friendly_name: ${friendly_name}
  # Automatically add the mac address to the name
  # so you can use a single firmware for all devices
  name_add_mac_suffix: true

  # hello world
  on_boot:
    priority: -100
    then:
    - light.turn_on:
        id: led1
        effect: HelloWorld
    - delay: 1000ms
    - light.turn_off: led1
    - wait_until:
        condition:
          api.connected:
        timeout: 20s
    - text_sensor.template.publish:
        id: status
        state: "Ready"

esp32:
  board: m5stack-atom
  watchdog_timeout: 15s
  framework:
    type: esp-idf

# To be able to get logs from the device via serial and api.
logger:
  # level: VERBOSE
  level: DEBUG
  # level: WARN
  logs:
    light: WARN
    # pn532: DEBUG
    # pn532_i2c: DEBUG

i2c:
  id: bus_i2c
  sda: 26
  scl: 32
  scan: False
  frequency: 100kHz
  timeout: 13ms #to prevent pn532 timeout

esp32_ble_tracker:
  scan_parameters:
    active: false
bluetooth_proxy:
  active: false

light:
  - platform: esp32_rmt_led_strip
    id: led1
    pin: GPIO27
    chipset: SK6812
    num_leds: 1
    rgb_order: grb
    restore_mode: ALWAYS_OFF
    default_transition_length: 0s
    flash_transition_length: 0s
    effects:
      - strobe:
          name: HelloWorld
          colors:
            - state: true
              brightness: 100%
              red: 100%
              green: 0%
              blue: 0%
              duration: 250ms
            - state: true
              brightness: 100%
              red: 0%
              green: 100%
              blue: 0%
              duration: 250ms
            - state: true
              brightness: 100%
              red: 0%
              green: 0%
              blue: 100%
              duration: 250ms
            - state: true
              brightness: 100%
              red: 100%
              green: 100%
              blue: 100%
              duration: 250ms
      - strobe:
          name: TagWrite
          colors:
            - state: true
              brightness: 100%
              red: 100%
              green: 0%
              blue: 0%
              duration: 250ms
            - state: false
              duration: 50ms

binary_sensor:
  - platform: gpio
    id: toggle
    pin:
      number: GPIO39
      inverted: true
    on_multi_click:
    - timing:
        - ON for at most 1s
        - OFF for at most 0.25s
        - ON for at most 1s
        - OFF for at most 0.25s
        - ON for at most 1s
      then:
        - script.execute: led_blink
        - text_sensor.template.publish:
            id: status
            state: "clickTriple"
        - script.execute:
            id: tagtuner_event
            action: "clickTriple"
            uid: ""
            uri: ""
            artist: ""
            playlist: ""
    - timing:
        - ON for at most 1s
        - OFF for at most 0.25s
        - ON for at most 1s
        - OFF for at least 0.25s
      then:
        - script.execute: led_blink
        - text_sensor.template.publish:
            id: status
            state: "clickDouble"
        - script.execute:
            id: tagtuner_event
            action: "clickDouble"
            uid: ""
            uri: ""
            artist: ""
            playlist: ""
    - timing:
        - ON for 0.5s to 2s
        - OFF for at least 50ms
      then:
        - script.execute: led_blink
        - text_sensor.template.publish:
            id: status
            state: "clickLong"
        - script.execute:
            id: tagtuner_event
            action: "clickLong"
            uid: ""
            uri: ""
            artist: ""
            playlist: ""
    - timing:
        - ON for at most 0.5s
        - OFF for at least 260ms
      then:
        - script.execute: led_blink
        - text_sensor.template.publish:
            id: status
            state: "clickSingle"
        - script.execute:
            id: tagtuner_event
            action: "clickSingle"
            uid: ""
            uri: ""
            artist: ""
            playlist: ""
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

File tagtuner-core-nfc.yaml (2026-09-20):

binary_sensor:
  - platform: template
    name: "=Tag="
    id: is_tag
    device_class: vibration
    entity_category: DIAGNOSTIC
    disabled_by_default: true

  - platform: template
    name: "=Reading="
    id: txt_reading
    device_class: running
    entity_category: DIAGNOSTIC
    lambda: |-
      if ( !id(pn532_board).is_writing() ) {
        return true;
      } else {
        return false;
      }
  - platform: template
    name: "=Writing="
    id: txt_writing
    device_class: running
    entity_category: DIAGNOSTIC
    lambda: |-
      if ( id(pn532_board).is_writing() ) {
        return true;
      } else {
        return false;
      }

script:
  - id: wait_input
    then:
      - delay: 3s
      - text_sensor.template.publish:
          id: status
          state: "Waiting for input"
  - id: set_tag
    then:
      - text.set:
          id: playlist_artist
          value: !lambda |-
            return id(artist);
      - delay: 10ms
      - text.set:
          id: playlist_info
          value: !lambda |-
            return id(playlist);
      - delay: 10ms
      - text.set:
          id: playlist_uri
          value: !lambda |-
            ESP_LOGD("tagtuner", "URI NDEF");
            return id(uri);

text:
  - platform: template
    id: playlist_artist
    name: "Playlist artist"
    icon: mdi:account-music
    # entity_category: CONFIG
    optimistic: true
    min_length: 0
    max_length: 50
    mode: text
    initial_value: " "
  - platform: template
    id: playlist_info
    name: "Playlist name or album title"
    icon: mdi:playlist-music
    # entity_category: CONFIG
    optimistic: true
    min_length: 0
    max_length: 100
    mode: text
    initial_value: " "
  - platform: template
    id: playlist_uri
    name: "Playlist URI"
    icon: mdi:link-variant
    # entity_category: CONFIG
    optimistic: true
    min_length: 0
    max_length: 255
    mode: text
    initial_value: " "

text_sensor:
  - platform: template
    id: status
    name: "Status"
    icon: mdi:ladybug
    entity_category: DIAGNOSTIC
    on_value:
      if:
        condition:
          lambda: 'return id(status).state != "Waiting for input";'
        then:
        - script.stop: wait_input
        - script.execute: wait_input

button:
  - platform: restart
    name: "Restart"
    id: btn_restart
    entity_category: DIAGNOSTIC

  - platform: template
    name: Cancel writing 
    id: btn_cancel_writing
    icon: "mdi:broadcast-off"
    # entity_category: CONFIG
    on_press:
      then:
      - lambda: 'id(pn532_board).read_mode();'
      - wait_until:
          timeout: 30s
          condition:
            not:
              pn532.is_writing:
      - delay: 5ms
      - text_sensor.template.publish:
          id: status
          state: "Cancel writing tag"
      - script.execute: led_ok

  - platform: template
    name: Erase Tag
    id: btn_erase_tag
    icon: "mdi:nfc-search-variant"
    # entity_category: CONFIG
    on_press:
      then:
      - script.execute: led_tagwrite
      - text.set:
          id: playlist_artist
          value: ''
      - text.set:
          id: playlist_info
          value: ''
      - text.set:
          id: playlist_uri
          value: ''
      - lambda: 'id(pn532_board).format_mode();'
      - text_sensor.template.publish:
          id: status
          state: "Place tag"
      - wait_until:
          timeout: 30s
          condition:
            not:
              pn532.is_writing:
      - if:
          condition:
            pn532.is_writing:
          then:
          - lambda: 'id(pn532_board).read_mode();'
      - text_sensor.template.publish:
          id: status
          state: "Finished erasing tag"
      - script.execute: led_success
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

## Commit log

2024-10-27 version 241027
    it all starts now
    [TagTunerAtomEchoGroveBase.stl, TagTunerAtomEchoGrovePlate.stl, TagTunerRecordCard.stl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]
2024-11-05 TagTuner for tagreader
    Adonno tagreader device support
2024-11-28 models upgrade
    thicker screw mounts in the base
    less shallow hole in the knob
    flat record card
    [TagTunerAtomEchoGroveBase.stl, TagTunerAtomEchoGrovePlate.stl, TagTunerRecordCard.stl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]
2024-12-02 ble version as default for esp32
    only stable CI testing
    grove ble version as default
2024-12-02 buzz switch (#7)
    light&buzz
2024-12-15 D1-custom v2412 (#9)
    Custom configuration for ESP32 D1 mini
2024-12-15 D1-case
    printables link
2025-01-04 blueprint v2501 (#10)
    New Music Assistant 2412 compatible
    tag scanned announcements
    triple click previous track
    minor updates:
    default NO_MASS player
    changed music_assistant filter selector
    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
2026-09-20 wifi debug sensors (#77)
